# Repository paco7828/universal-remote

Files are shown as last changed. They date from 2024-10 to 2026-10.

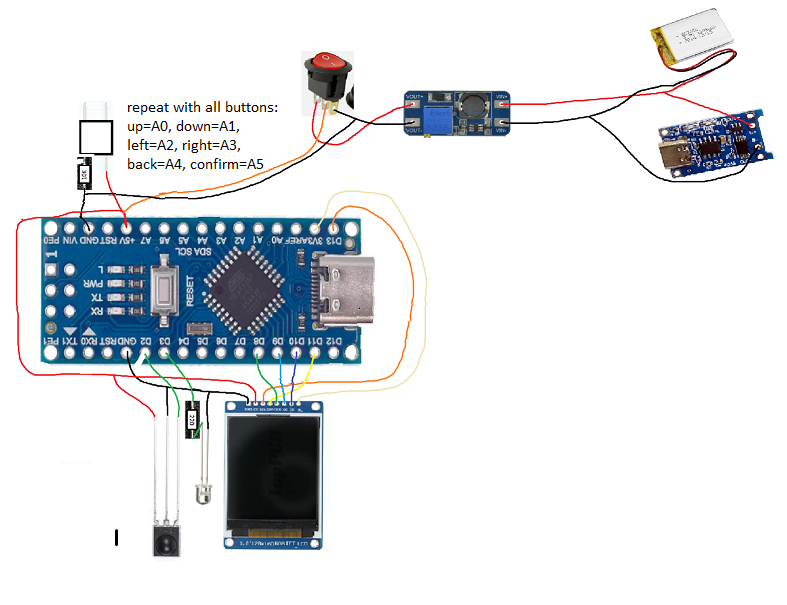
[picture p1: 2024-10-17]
demo/wiring-paint-1.PNG

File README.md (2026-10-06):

# Universal Remote

ESP32-based universal infrared remote control with touch screen.
It can **learn** IR signals, **save them to an SD card**, **resend** them,
and transmit **built-in brand codes**.
The entire UI is touch-controlled, featuring scrollable lists and a virtual
keyboard.

---

## Hardware

| Component | Description |
|---|---|
| MCU | ESP32 (Using FSPI / SPI2 bus) |
| Display | ILI9341 2.4" TFT, 240x320, portrait (rotation 0) |
| Touch | XPT2046 resistive touch, via SPI |
| Storage | MicroSD card |
| IR Transmitter| TSAL6200 |
| IR Receiver | IRM-3638T |

The display and the SD card use **the same SPI bus** (shared MOSI/MISO/CLK),
multiplexed with CS lines. Before sending an IR signal, the code sets `SD_CS` and `TOUCH_CS`
HIGH to avoid bus conflicts.

### Pinout

| Signal | GPIO |
|---|---|
| TFT CS | 7 |
| TFT RST | 10 |
| TFT DC | 2 |
| TFT MOSI | 6 |
| TFT MISO | 5 |
| TFT CLK | 4 |
| Touch CS | 8 |
| Touch IRQ | 9 |
| SD CS | 3 |
| IR TX | 0 |
| IR RX | 1 |

---

## Dependencies

- **LovyanGFX** - display + touch driver (ILI9341 + XPT2046)
- **IRremoteESP8266** - IR receive / send / decode
- **Preferences** - ESP32 NVS (for saving themes)
- **SD**, **SPI** - Arduino ESP32 core built-in
- **`./IR-codes.h`** - custom header with built-in Pronto Hex codes
  (EPSON and NEC arrays). **Without this, the project will not compile.**

---

## Features

### Signal learning (Receive)

1. `Signal options -> Receive` starts listening mode.
2. The receiver decodes the signal into `decode_results`.
3. The code accepts a **maximum of 3 frames** at once within a signal
   (`MAX_FRAMES = 3`), measuring the pause between them as `gap_ms`.
4. Repeat frames and identical frames are discarded.
5. An `UNKNOWN` (raw) signal is only accepted if it is the **first** frame,
   and contains at least 10 pulses, filtering out noise.
6. The captured signal type is determined automatically:
   - `SIG_VALUE` - known protocol, fixed-length value (e.g., NEC)
   - `SIG_STATE` - AC-like protocols with byte-array states
   - `SIG_RAW` - unknown, raw microsecond array
7. After capture, a **QWERTY keyboard** appears to name the signal
   (max 25 characters, letters + `-`).
8. Saved to the SD card: `/saved-signals/<group>/<name>.txt`.

### Signal sending (Transmit)

- **Saved signals**: `Signal options -> Transmit` -> group list -> signal list -> Send.
  The group is the part of the signal's name before the `-` (e.g., `TV-power` -> `TV` group).
- **Built-in signals**: `Built-in signals` -> brand -> signal -> Send.
- **Long pressing** the `Send` button repeats the signal (except for `SIG_STATE` signals).
- Transmission strategy:
  - `SIG_VALUE`: `irsend.send(protocol, value, bits)` - for RC5/RC6,
    the toggle bit switches automatically on each new press.
  - `SIG_STATE`: `irsend.send(protocol, state, bytes)`.
  - `SIG_RAW`: `irsend.sendRaw(rawData, len, khz)`.
  - If protocol sending returns `false`, but raw data is available, an
    automatic **raw fallback** occurs.
- For multi-frame signals, there is a `gap_ms` pause between frames.

### Built-in signals

The `IRCode` structures declared in `IR-codes.h` store the codes in Pronto Hex format.
The firmware converts them to raw microsecond arrays using the `prontoToRawSignal()`
function and calculates the carrier frequency with `prontoCarrierKHz()`.

Currently, **only these** are available from the UI in the `hardcodedBrands[]` array:

- EPSON
- NEC

(Other brands will only appear if you add them to the array.)

### SD Card Management

- **Info** - total / free / used space + number of saved signal files.
- **Files** - file browser with directory navigation, size display,
  and individual file deletion (`Del` button, **!NO CONFIRMATION MESSAGE!**).
- **Format** - keeps the `/System Volume Information` and `/built-in-signals`
  directories, deletes everything else.
- File list limit: 500 items.

### UI / Themes

Three selectable color themes (persisted in NVS):

- Futuristic Red (default)
- Futuristic Green
- Futuristic Purple

Theme switching is displayed with an animated spreading circle effect.

Other UI features:

- Boot splash: `UNIVERSAL / REMOTE` text for ~2 seconds.
- **Scrollable lists** with a sprite buffer (`LGFX_Sprite`) to prevent flickering.
- **Double tap** on a list item = open.
- **Long hold** on a repeatable button = rapid fire (`REPEAT_INTERVAL = 200 ms`).
- Maximum number of buttons per screen: **30**.
- Button style: corner accents + scanline pattern.

---

## Navigation Structure

```
Main Menu
├── Signal options
│   ├── Transmit  ->  [Group]  ->  [Signal list]  ->  Send
│   └── Receive   ->  Listening... ->  Captured!   ->  Keyboard -> Save
├── Built-in signals
│   └── [Brand]   ->  [Signal list] ->  Send
├── SD Card options
│   ├── Info
│   ├── Files  ->  browser (Up / Back / Del)
│   └── Format ->  Yes, format / Cancel formatting
└── Change theme
    ├── Futuristic Red
    ├── Futuristic Green
    └── Futuristic Purple
```

If SD initialization fails, "SD Card options" disappears from the main menu.

---

## Saved signal file format

**Not binary** - each signal is a simple, line-separated `.txt` file:

```
# UniRemote IR signal
name: TV-power
carrier_khz: 38
frame: 1
gap_ms: 40
protocol: NEC
bits: 32
value: 0x20DF10EF
length: 68
raw: 9000,4500,560,560,...
frame: 2
...
```

Fields per frame:

- `gap_ms` - pause before the next frame (only if there is a next frame)
- `protocol` - name returned by `typeToString()`
- `bits` - number of bits for `SIG_VALUE`, bytes×8 for `SIG_STATE`
- `value` - hex value (`SIG_VALUE`)
- `bytes` - space-separated hex bytes (`SIG_STATE`)
- `length` + `raw` - raw microsecond array (always saved if available)

When loading the file, the code automatically determines the `kind` based
on the existing fields: value -> state -> raw priority.

Folder structure:

```
/saved-signals/
├── TV/
│   ├── power.txt
│   └── mute.txt
├── Misc/
│   └── random-signal.txt
```

Names without `-` are automatically placed in the `Misc` group.

---

## File structure

| File | Role |
|---|---|
| `UniversalRemote.ino` | Full firmware |
| `IR-codes.h` | Built-in Pronto Hex codes (EPSON, NEC arrays, `IRCode` struct) |

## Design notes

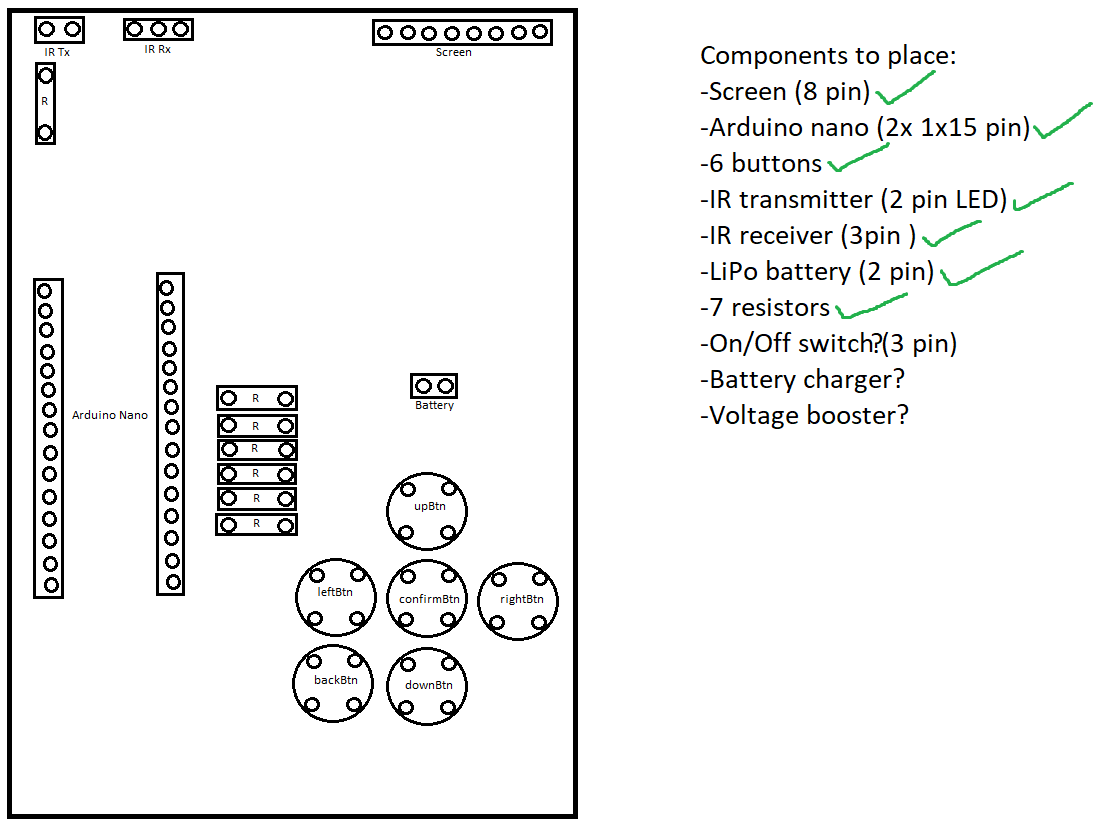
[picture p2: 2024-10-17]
demo/pcb_plan.PNG

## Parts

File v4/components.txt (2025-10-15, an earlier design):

1x ESP32 C3 SUPERMINI - https://www.hestore.hu/prod_10048018.html
3x 100nF 0805 capacitor - https://www.hestore.hu/prod_10001122.html
1x 100uF electrolytic capacitor - https://www.hestore.hu/prod_10039018.html
1x 2.8" TFT Touch display - https://www.hestore.hu/prod_10047949.html
1x 100R 0805 resistor - https://www.hestore.hu/prod_10001142.html
1x 100kR 0805 resistor - https://www.hestore.hu/prod_10001143.html
1x AO3400A - https://www.hestore.hu/prod_10039959.html
1x IRE940-5 - https://www.hestore.hu/prod_10041889.html
1x 22R 1W 2512 resistor - https://www.hestore.hu/prod_10031720.html
1x IRM3638T - https://www.hestore.hu/prod_10045411.html
1x B2B-XH-A - https://www.hestore.hu/prod_10041549.html
1x KCD11-2P - https://www.hestore.hu/prod_10047980.html
1x USB-C-6 pin - https://www.hestore.hu/prod_10046971.html
2x 1N5819HW-7-F - https://www.hestore.hu/prod_10046229.html
1x Red LED 0805 - https://www.hestore.hu/prod_10043215.html
1x Green LED 0805 - https://www.hestore.hu/prod_10036384.html
3x 1kR 0805 resistor - https://www.hestore.hu/prod_10031299.html
2x 10uF 0805 capacitor - https://www.hestore.hu/prod_10032047.html
1x TP4056 - https://www.hestore.hu/prod_10037291.html
1x 1.2kR resistor - https://www.hestore.hu/prod_10001268.html
1x DW01A - https://www.hestore.hu/prod_10046612.html
1x 8205A - https://www.hestore.hu/prod_10045032.html
1x MT3608 - https://www.hestore.hu/prod_10048950.html
1x 22uH 0705 inductor - https://www.hestore.hu/prod_10046500.html
1x 7.5kR 0805 resistor - https://www.hestore.hu/prod_10001197.html

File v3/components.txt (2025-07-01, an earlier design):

ATMEGA328P-AU - https://www.hestore.hu/prod_10032542.html
10k resistor - https://www.hestore.hu/prod_10040338.html
CH340G - https://www.hestore.hu/prod_10036442.html
100nF capacitor - https://www.hestore.hu/prod_10001122.html
3x 22R resistor - https://www.hestore.hu/prod_10001250.html
12MHz crystal - https://www.hestore.hu/prod_10021387.html
16MHz crystal - https://www.hestore.hu/prod_10021434.html
4x 22pF capacitor - https://www.hestore.hu/prod_10001131.html
Micro USB - https://www.hestore.hu/prod_10032693.html
6x SMD button - https://www.hestore.hu/prod_10043772.html
IR transmitter - https://www.hestore.hu/prod_10041889.html
NPN transistor - https://www.hestore.hu/prod_10020924.html
220 resistor - https://www.hestore.hu/prod_10001162.html
IR receiver - https://www.hestore.hu/prod_10045411.html
1.8" TFT screen - https://www.hestore.hu/prod_10045986.html
1x 10uF capacitor - https://www.hestore.hu/prod_10032047.html
Battery protection IC - https://www.hestore.hu/prod_10046612.html
N-channel MOSFET - https://www.hestore.hu/prod_10045032.html
Battery charger IC - https://www.hestore.hu/prod_10037291.html
Green led - https://www.hestore.hu/prod_10036384.html
Red led - https://www.hestore.hu/prod_10043215.html
2x 1k resistors - https://www.hestore.hu/prod_10031299.html
1.2k resistor - https://www.hestore.hu/prod_10001268.html
Battery - https://www.hestore.hu/prod_10036161.html
Battery JST connector - https://www.hestore.hu/prod_10038523.html
Step up converter IC - https://www.hestore.hu/prod_10032041.html
4.7uF capacitor - https://www.hestore.hu/prod_10033975.html
4.7uH inductor - https://www.hestore.hu/prod_10047163.html
1.5M resistor - https://www.hestore.hu/prod_10001251.html
470k resistor - https://www.hestore.hu/prod_10001179.html
Schottky diode - https://www.hestore.hu/prod_10039694.html
Power switch - https://www.hestore.hu/prod_10022003.html

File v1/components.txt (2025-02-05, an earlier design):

-microcontroller - AR-NANOCH-UNS-TYPE-C - https://www.hestore.hu/prod_10044467.html#
-step up module - MT3608-2A - https://www.hestore.hu/prod_10038537.html#
-IR receiver - IRM-3638T - https://www.hestore.hu/prod_10045411.html
-IR blaster - IRE940-5 - https://www.hestore.hu/prod_10041889.html
-power switch - LVSR-12-RD - https://www.hestore.hu/prod_10036786.html
-battery charger module - TP4056-1A-USBC - https://www.hestore.hu/prod_10042093.html
-battery - KXD 383450PL M - https://www.hestore.hu/prod_10036161.html
-Resistors:
    -IR blaster - 220 R 1% - https://www.hestore.hu/prod_10020500.html
    -6x for buttons - 10 K 1% - https://www.hestore.hu/prod_10020541.html
-Screen - 1.8 Inch 8Pin 128*160 RGB TFT LCD Screen Display Module SPI Interface ST7735 IC Driver - https://www.aliexpress.com/i/32988162684.html

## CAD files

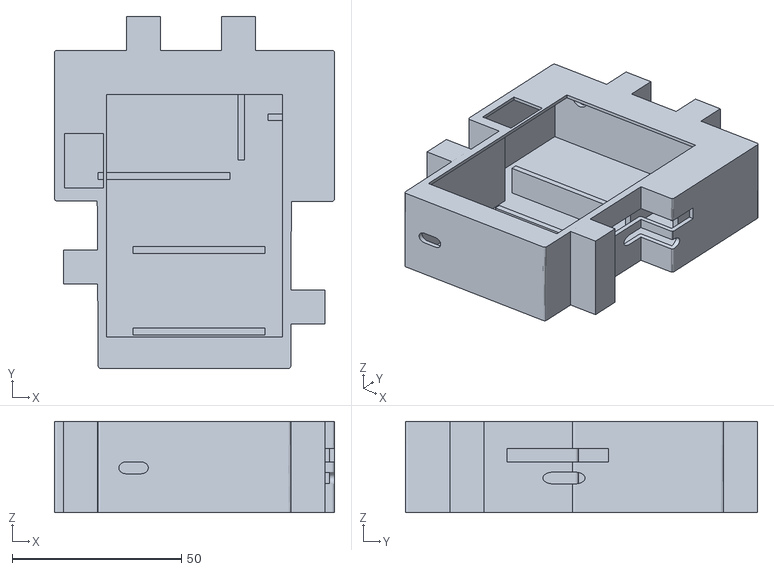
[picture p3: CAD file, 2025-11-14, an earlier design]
v4/uniremote.stl
82.7 x 103.9 x 27.0

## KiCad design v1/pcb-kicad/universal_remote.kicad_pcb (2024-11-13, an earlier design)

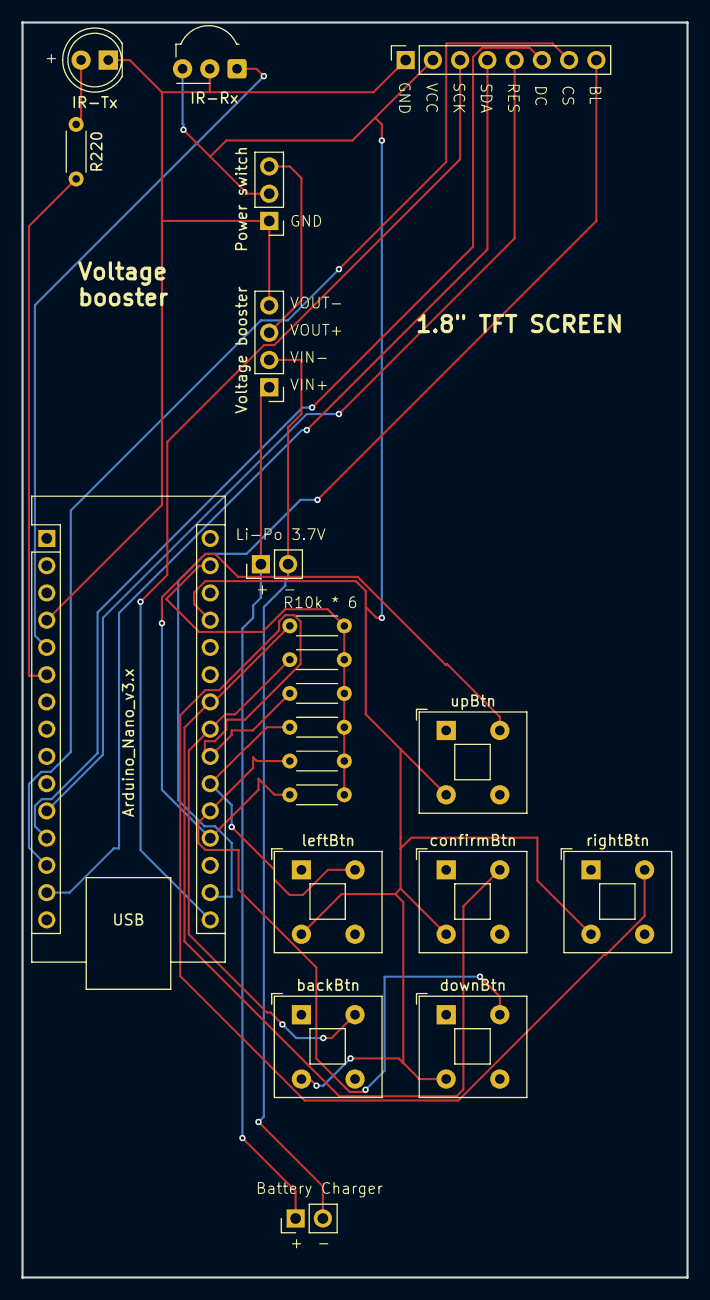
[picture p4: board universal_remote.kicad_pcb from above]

Board: 2 copper layers, 62.0 x 117.0 mm, 21 parts (0 on the bottom side), 21 nets.

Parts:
A1: Arduino_Nano_v3.x; Arduino_Nano
BT1: Li-Po-3.7V; PinHeader_1x02_P2.54mm_Vertical
IR-Tx: IR-Tx; LED_D5.0mm_IRGrey
J1: 1.8TFT-SCREEN; PinSocket_1x08_P2.54mm_Vertical
J2: Battery charger; PinHeader_1x02_P2.54mm_Vertical
J3: Voltage booster; PinHeader_1x04_P2.54mm_Vertical
J4: Power switch; PinHeader_1x03_P2.54mm_Vertical
R2, R3, R4, R5, R6, R7: 1K; R_Axial_DIN0204_L3.6mm_D1.6mm_P5.08mm_Horizontal
R220: 220; R_Axial_DIN0204_L3.6mm_D1.6mm_P5.08mm_Horizontal
U1: IR-Rx; Vishay_MOLD-3Pin
backBtn: backBtn; SW_Push_2P1T_Toggle_CK_PVA1xxH2xxxxxxV2
confirmBtn: confirmBtn; SW_Push_2P1T_Toggle_CK_PVA1xxH2xxxxxxV2
downBtn: downBtn; SW_Push_2P1T_Toggle_CK_PVA1xxH2xxxxxxV2
leftBtn: leftBtn; SW_Push_2P1T_Toggle_CK_PVA1xxH2xxxxxxV2
rightBtn: rightBtn; SW_Push_2P1T_Toggle_CK_PVA1xxH2xxxxxxV2
upBtn: upBtn; SW_Push_2P1T_Toggle_CK_PVA1xxH2xxxxxxV2

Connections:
unnamed: A1.17 (3V3), J1.8
unnamed: A1.27 (+5V), J1.2, J4.2, U1.3 (Vs), backBtn.3 (B), backBtn.4 (B), confirmBtn.3 (B), confirmBtn.4 (B), downBtn.3 (B), downBtn.4 (B), leftBtn.3 (B), leftBtn.4 (B), rightBtn.3 (B), rightBtn.4 (B), upBtn.3 (B), upBtn.4 (B)
unnamed: A1.19 (A0), R2.2, upBtn.1 (A), upBtn.2 (A)
unnamed: A1.20 (A1), R3.2, downBtn.1 (A), downBtn.2 (A)
unnamed: A1.21 (A2), R4.2, leftBtn.1 (A), leftBtn.2 (A)
unnamed: A1.22 (A3), R5.2, rightBtn.1 (A), rightBtn.2 (A)
unnamed: A1.23 (A4), R6.2, backBtn.1 (A), backBtn.2 (A)
unnamed: A1.24 (A5), R7.2, confirmBtn.1 (A), confirmBtn.2 (A)
unnamed: A1.5 (D2), U1.1 (OUT)
unnamed: A1.6 (D3), R220.2
unnamed: A1.11 (D8), J1.5
unnamed: A1.12 (D9), J1.6
unnamed: A1.13 (D10), J1.7
unnamed: A1.14 (D11), J1.4
unnamed: A1.16 (D13), J1.3
unnamed: A1.29 (GND), R2.1, R3.1, R4.1, R5.1, R6.1, R7.1
unnamed: BT1.1 (+), J2.1, J3.1
unnamed: BT1.2 (-), J2.2, J3.2
unnamed: IR-Tx.2 (A), R220.1
unnamed: A1.4 (GND), IR-Tx.1 (K), J1.1, J3.4, J4.1, U1.2 (GND)
unnamed: J3.3, J4.3

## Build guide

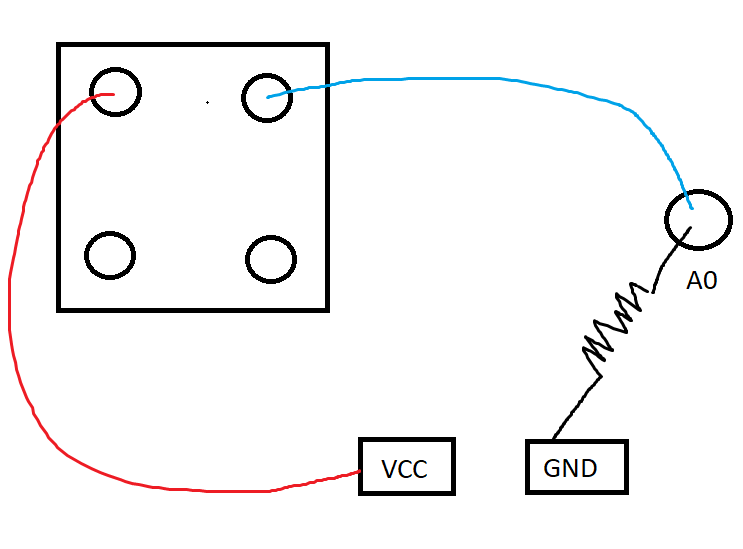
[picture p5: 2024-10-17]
demo/CORRECT_SOLDER.PNG

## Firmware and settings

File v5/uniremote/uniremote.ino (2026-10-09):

#define LGFX_USE_V1
#include <LovyanGFX.hpp>
#include <SPI.h>
#include <SD.h>
#include <IRremoteESP8266.h>
#include <IRrecv.h>
#include <IRsend.h>
#include <IRutils.h>
#include <Preferences.h>
#include <functional>
#include <vector>
#include <algorithm>
#include "./IR-codes.h"

// ============================================================
// Layout of this file
//   1. Pins, display driver
//   2. Constants, types, theme presets
//   3. Function prototypes (grouped by module)
//   4. Static data (menu tables, built-in brand table)
//   5. Global state (grouped by module)
//   6. Setup & loop
//   7. UI core: display chrome, touch & buttons, scroll list engine
//   8. IR engine, signal storage (SD), SD utilities
//   9. Screens: main menu, signals, built-in, SD card, theme
// ============================================================

// ============================================================
// Pin definitions
// ============================================================
constexpr uint8_t TFT_CS = 7;
constexpr uint8_t TFT_RST = 10;
constexpr uint8_t TFT_DC = 2;
constexpr uint8_t TFT_MOSI = 6;
constexpr uint8_t TFT_MISO = 5;
constexpr uint8_t TFT_CLK = 4;
constexpr uint8_t TOUCH_CS = 8;
constexpr uint8_t TOUCH_IRQ = 9;
constexpr uint8_t SD_CS = 3;
constexpr uint8_t IR_TX = 0;
constexpr uint8_t IR_RX = 1;

// ============================================================
// Display driver
// ============================================================
class LGFX : public lgfx::LGFX_Device {
  lgfx::Panel_ILI9341 _panel_instance;
  lgfx::Bus_SPI _bus_instance;
  lgfx::Touch_XPT2046 _touch_instance;
public:
  LGFX(void) {
    {
      auto cfg = _bus_instance.config();
      cfg.spi_host = SPI2_HOST;
      cfg.spi_mode = 0;
      cfg.freq_write = 40000000;
      cfg.freq_read = 16000000;
      cfg.pin_sclk = TFT_CLK;
      cfg.pin_mosi = TFT_MOSI;
      cfg.pin_miso = -1;
      cfg.pin_dc = TFT_DC;
      _bus_instance.config(cfg);
      _panel_instance.setBus(&_bus_instance);
    }
    {
      auto cfg = _panel_instance.config();
      cfg.pin_cs = TFT_CS;
      cfg.pin_rst = TFT_RST;
      cfg.panel_width = 240;
      cfg.panel_height = 320;
      _panel_instance.config(cfg);
    }
    {
      auto cfg = _touch_instance.config();
      cfg.x_min = 3850;
      cfg.x_max = 240;
      cfg.y_min = 250;
      cfg.y_max = 3750;
      cfg.pin_sclk = TFT_CLK;
      cfg.pin_mosi = TFT_MOSI;
      cfg.pin_miso = TFT_MISO;
      cfg.pin_cs = TOUCH_CS;
      cfg.pin_int = TOUCH_IRQ;
      cfg.bus_shared = true;
      cfg.spi_host = SPI2_HOST;
      cfg.freq = 1000000;
      _touch_instance.config(cfg);
      _panel_instance.setTouch(&_touch_instance);
    }
    setPanel(&_panel_instance);
  }
};

// ============================================================
// Constants
// ============================================================
// --- UI layout: scroll list viewport shared by every list screen ---
constexpr int LIST_VIEW_X = 5;
constexpr int LIST_VIEW_Y = 26;
constexpr int LIST_VIEW_W = 230;
constexpr int LIST_VIEW_H = 228;
constexpr int LIST_BUTTON_Y = 260;

// --- Touch timing ---
constexpr unsigned long REPEAT_INTERVAL = 200;
constexpr int SCROLL_DRAG_THRESHOLD = 10;
constexpr unsigned long DOUBLE_TAP_WINDOW = 400;

// --- IR capture / transmit ---
constexpr uint16_t IR_CAPTURE_BUFFER = 1024;
constexpr uint8_t IR_CAPTURE_TIMEOUT_MS = 35;
constexpr uint16_t IR_FRAME_WINDOW_MS = 400;
constexpr uint8_t MAX_FRAMES = 3;
constexpr uint16_t MAX_RAW_PULSES = 400;
constexpr uint8_t DEFAULT_CARRIER_KHZ = 38;
constexpr uint16_t IR_DEFAULT_GAP_MS = 40;
constexpr uint16_t IR_VARIANT_GAP_MS = 50;
constexpr float PRONTO_CLOCK_US = 0.241246f;

// --- Signal storage on SD ---
constexpr const char *SAVED_ROOT = "/saved-signals";
constexpr const char *SIGNAL_EXT = ".txt";
constexpr int MAX_SAVED_SIGNAL_CHARS = 25;
constexpr int SD_FILES_MAX = 500;

// ============================================================
// Types
// ============================================================
enum SignalKind : uint8_t { SIG_RAW = 0,
                            SIG_VALUE = 1,
                            SIG_STATE = 2 };
enum CaptureResult : uint8_t { CAP_IGNORED,
                               CAP_INVALID,
                               CAP_OK };

struct IRSignal {
  char name[MAX_SAVED_SIGNAL_CHARS + 1];
  SignalKind kind;
  decode_type_t protocol;
  uint16_t bits;
  uint64_t value;
  uint8_t state[kStateSizeMax];
  uint8_t carrierKHz;
  uint16_t rawData[MAX_RAW_PULSES];
  uint16_t rawDataLen;
  uint16_t gapAfterMs;
};

struct TouchButton {
  int x, y, w, h;
  uint16_t color;
  const char *label;
  void (*callback)();
  bool pressed, isBackButton, repeatable;
};

using RowRenderer = std::function<void(int idx, int y, int rowH, bool selected)>;

struct ScrollList {
  int itemCount = 0;
  int rowHeight = 32;
  int selectedIndex = -1;
  float scrollPx = 0;
  int viewX = 0, viewY = 0, viewW = 0, viewH = 0;
  RowRenderer renderRow;
  std::function<void()> onOpen = nullptr;
  std::function<void()> onSelect = nullptr;
};

struct Option {
  const char *name;
  void (*callback)();
};

struct ThemeColors {
  uint16_t primary, secondary, accent, dark, darkest;
};

struct HardcodedBrand {
  const char *brandName;
  const IRCode *codes;
  uint8_t codesLength;
};

// ============================================================
// Theme presets
// ============================================================
const ThemeColors THEME_FUTURISTIC_RED = { 0xF800, 0xD000, 0x8800, 0x4208, 0x2104 };
const ThemeColors THEME_FUTURISTIC_GREEN = { 0x07E0, 0x05C0, 0x0400, 0x4208, 0x2104 };
const ThemeColors THEME_FUTURISTIC_PURPLE = { 0xF81F, 0xC81F, 0x8010, 0x4208, 0x2104 };

// ============================================================
// Function prototypes
// ============================================================
// Setup & loop
void initHardware();
void pollIRCapture();
void pollTouch();

// Display chrome
void clearScreen();
void beginScreen();
void drawHeaderFooter();
void drawTitle(const char *title, uint16_t x = 90, uint16_t y = 305);
void drawBackBtn(uint8_t x, uint8_t y, uint8_t w, uint8_t h, void (*cb)());
void printCentered(const char *text, int y, uint16_t color, uint8_t size);
void showEmptyScreen(const char *line1, const char *line2, int y, void (*backCb)(), const char *title, uint16_t titleX);
void drawBootSplash();

// Touch & buttons
int processTouchButtons(int tx, int ty);
bool isTouchInButton(TouchButton *btn, int tx, int ty);
void drawButton(TouchButton *btn, bool active);
void createTouchBox(int x, int y, int w, int h, uint16_t color, const char *label, void (*cb)(), bool isBack = false, bool repeatable = false);
void createOptions(const Option opts[], int count, int x = 10, int y = 50, int bw = 220, int bh = 45);

// Scroll list engine
bool pointInScrollView(ScrollList *list, int x, int y);
void ensureListSprite(int w, int h);
void clampScroll(ScrollList &list);
void renderScrollList(ScrollList &list);
void setupAndRenderScrollList(int count, int rowH, RowRenderer renderer);
void resetListSelection();
bool selectionValid(size_t count);
void drawListRow(int y, int rowH, bool selected, const String &text, uint8_t textSize = 2);

// IR engine
CaptureResult captureFrame(const decode_results &r, unsigned long nowMs);
void transmitSignal(const IRSignal &signal);
void transmitSequence(const IRSignal *frames, uint8_t count);
uint8_t prontoCarrierKHz(const uint16_t *pronto);
uint16_t prontoToRawSignal(const uint16_t *pronto, uint16_t *outRaw);
uint8_t codeVariants(const IRCode &code);
void sendBuiltInVariant(const IRCode &code, uint8_t variant);

// Signal storage (SD)
void sortNames(std::vector<String> &v);
void splitSignalName(const char *full, String &group, String &file);
void migrateFlatSignals();
bool isSignalFile(const String &fileName);
String stripSignalExt(String fileName);
void saveSignalToSD(const IRSignal *frames, uint8_t count);
bool loadSignalFromSD(const String &fileName, IRSignal *frames, uint8_t &count);

// SD utilities
String formatBytes(uint64_t bytes);
int countFilesInDirectory(const char *path);
bool deleteDirectory(const char *path);
void formatStatusLine(const char *label, uint16_t labelColor, const String &name);

// Screens: main menu
void drawMenuUI();

// Screens: signals (transmit / receive / keyboard)
void signalOptions();
void listSavedSignals();
void drawSavedSignalsList();
void listGroupedSignals();
void drawGroupedSignalsList();
void startSignalListen();
void drawKeyboard();
void keyboardButtonPressed();
void leaveKeyboard();

// Screens: built-in signals
void builtInSignalsBrowser();
void listBuiltInSignals();
void listBuiltInVariants();
void updateBuiltInButtons(bool force);

// Screens: SD card
void sdData();
void listSDInfo();
void listSDFiles();
void browseSDPath(const String &path);
void loadSDFiles(const String &path);
void drawSDFileBrowser();
void sdFormatOptions();
void formatSD();
void deleteSelectedFile();

// Screens: theme
void themeOptions();
void setThemeFuturisticRed();
void setThemeFuturisticGreen();
void setThemeFuturisticPurple();
ThemeColors themeFromIndex(uint8_t idx);
void setTheme(uint8_t themeIndex);

// ============================================================
// Static data (menus & brand library)
// ============================================================
const Option MENU_OPTIONS[] = {
  { "Signal options", signalOptions },
  { "Built-in signals", builtInSignalsBrowser },
  { "SD Card options", sdData },
  { "Change theme", themeOptions }
};
const Option MENU_OPTIONS_NO_SD[] = {
  { "Signal options", signalOptions },
  { "Built-in signals", builtInSignalsBrowser },
  { "Change theme", themeOptions }
};
const Option SD_CARD_OPTIONS[] = {
  { "Info", listSDInfo },
  { "Files", listSDFiles },
  { "Format", sdFormatOptions },
  { "Back", drawMenuUI }
};
const Option SD_FORMAT_OPTIONS[] = {
  { "Yes, format", formatSD },
  { "Cancel formatting", sdData }
};
const Option THEME_OPTIONS[] = {
  { "Futuristic Red", setThemeFuturisticRed },
  { "Futuristic Green", setThemeFuturisticGreen },
  { "Futuristic Purple", setThemeFuturisticPurple },
  { "Back", drawMenuUI }
};

const HardcodedBrand hardcodedBrands[] = {
  { "EPSON", EPSON_CODES, EPSON_CODES_LENGTH },
  { "NEC", NEC_CODES, NEC_CODES_LENGTH },
  { "MIDEA", MIDEA_CODES, MIDEA_CODES_LENGTH }
};
const uint8_t hardcodedBrandsLength = sizeof(hardcodedBrands) / sizeof(hardcodedBrands[0]);

// ============================================================
// Global state
// ============================================================
// --- Display & preferences ---
LGFX tft;
SPIClass spiSD(FSPI);
ThemeColors currentTheme;
Preferences prefs;
bool initializedSD = false;

// --- Button system ---
TouchButton buttons[30];
uint8_t buttonCount = 0;
uint8_t activeBtnIndex = 0;

// --- Touch / gesture ---
bool touchHeld = false;
int heldButtonIndex = -1;
unsigned long lastRepeatFire = 0;
bool scrollGestureActive = false;
bool scrollIsDragging = false;
int32_t scrollStartY = 0;
float scrollStartPx = 0;
int lastTapIndex = -1;
unsigned long lastTapTime = 0;

// --- Scroll list engine ---
LGFX_Sprite listSprite(&tft);
bool listSpriteReady = false;
ScrollList activeList;
ScrollList *activeScrollList = nullptr;

// --- IR ---
IRrecv irrecv(IR_RX, IR_CAPTURE_BUFFER, IR_CAPTURE_TIMEOUT_MS, true);
IRsend irsend(IR_TX);
decode_results irResults;
IRSignal capturedFrames[MAX_FRAMES];
uint8_t capturedFrameCount = 0;
unsigned long lastFrameMs = 0;
bool signalCaptured = false;
bool listeningForSignal = false;
bool rcToggle = false;

// --- Saved signals browser ---
std::vector<String> savedSignalGroups;
std::vector<String> groupedSignalFiles;
String currentSavedGroup = "";
String sendCachePath;

// --- Built-in signals browser ---
const IRCode *currentBrandCodes = nullptr;
uint8_t currentBrandCodesLength = 0;
String currentBrandName = "";
const IRCode *currentCode = nullptr;

// --- SD file browser ---
std::vector<String> sdFiles;
String currentPath = "/";

// --- Keyboard ---
const char *const qwerty0[10] = { "Q", "W", "E", "R", "T", "Y", "U", "I", "O", "P" };
const char *const qwerty1[9] = { "A", "S", "D", "F", "G", "H", "J", "K", "L" };
const char *const qwerty2[7] = { "Z", "X", "C", "V", "B", "N", "M" };
char outputText[MAX_SAVED_SIGNAL_CHARS + 1] = "";

// ============================================================
// Setup & loop
// ============================================================
void setup() {
  initHardware();
}

void loop() {
  if (listeningForSignal && !signalCaptured) pollIRCapture();
  pollTouch();
  delay(listeningForSignal ? 1 : 10);
}

void pollIRCapture() {
  if (irrecv.decode(&irResults)) {
    unsigned long now = millis();
    CaptureResult cr = captureFrame(irResults, now);
    if (cr == CAP_INVALID) {
      beginScreen();
      printCentered("Invalid", 120, currentTheme.primary, 2);
      printCentered("signal!", 140, currentTheme.primary, 2);
      delay(2000);
      startSignalListen();
    }
  }

  bool done = capturedFrameCount > 0 && (capturedFrames[0].kind == SIG_RAW || capturedFrameCount >= MAX_FRAMES || millis() - lastFrameMs > IR_FRAME_WINDOW_MS);
  if (done) {
    irrecv.disableIRIn();
    signalCaptured = true;
    listeningForSignal = false;
    beginScreen();
    printCentered("Captured!", 150, currentTheme.primary, 2);
    delay(1500);
    drawKeyboard();
  }
}

void pollTouch() {
  int32_t tx, ty;
  bool touching = tft.getTouch(&tx, &ty);

  if (touching) {
    if (!touchHeld) {
      touchHeld = true;
      if (pointInScrollView(activeScrollList, (int)tx, (int)ty)) {
        scrollGestureActive = true;
        scrollIsDragging = false;
        scrollStartY = ty;
        scrollStartPx = activeScrollList->scrollPx;
        heldButtonIndex = -1;
      } else {
        scrollGestureActive = false;
        heldButtonIndex = processTouchButtons((int)tx, (int)ty);
        lastRepeatFire = millis();
      }
    } else if (scrollGestureActive && activeScrollList) {
      int32_t delta = ty - scrollStartY;
      if (!scrollIsDragging && abs((int)delta) > SCROLL_DRAG_THRESHOLD)
        scrollIsDragging = true;
      if (scrollIsDragging) {
        activeScrollList->scrollPx = scrollStartPx - delta;
        clampScroll(*activeScrollList);
        renderScrollList(*activeScrollList);
      }
    } else if (heldButtonIndex >= 0 && heldButtonIndex < buttonCount) {
      TouchButton *btn = &buttons[heldButtonIndex];
      if (btn->repeatable && isTouchInButton(btn, (int)tx, (int)ty)) {
        unsigned long now = millis();
        if (now - lastRepeatFire > REPEAT_INTERVAL) {
          lastRepeatFire = now;
          if (btn->callback) btn->callback();
          if (heldButtonIndex < buttonCount) {
            buttons[heldButtonIndex].pressed = true;
            drawButton(&buttons[heldButtonIndex], true);
          }
        }
      }
    }
    delay(scrollIsDragging ? 16 : 50);

  } else {
    if (scrollGestureActive && !scrollIsDragging && activeScrollList) {
      int relY = scrollStartY - activeScrollList->viewY;
      int tapped = (int)((activeScrollList->scrollPx + relY) / activeScrollList->rowHeight);
      if (tapped >= 0 && tapped < activeScrollList->itemCount) {
        unsigned long now = millis();
        bool isDoubleTap = (tapped == lastTapIndex) && (now - lastTapTime < DOUBLE_TAP_WINDOW);
        activeScrollList->selectedIndex = tapped;
        renderScrollList(*activeScrollList);
        if (isDoubleTap && activeScrollList->onOpen) {
          lastTapIndex = -1;
          activeScrollList->onOpen();
        } else {
          lastTapIndex = tapped;
          lastTapTime = now;
          if (activeScrollList->onSelect) activeScrollList->onSelect();
        }
      }
    }
    scrollGestureActive = false;
    scrollIsDragging = false;
    touchHeld = false;
    heldButtonIndex = -1;
    for (int i = 0; i < buttonCount; i++) {
      if (buttons[i].pressed) {
        buttons[i].pressed = false;
        drawButton(&buttons[i], false);
      }
    }
  }
}

void initHardware() {
  prefs.begin("uniremote", true);
  currentTheme = themeFromIndex(prefs.getUChar("theme", 0));
  prefs.end();

  irsend.begin();

  for (uint8_t cs : { TFT_CS, TOUCH_CS, SD_CS }) {
    pinMode(cs, OUTPUT);
    digitalWrite(cs, HIGH);
  }

  spiSD.begin(TFT_CLK, TFT_MISO, TFT_MOSI, SD_CS);
  initializedSD = SD.begin(SD_CS, spiSD, 20000000);
  if (initializedSD) {
    if (!SD.exists(SAVED_ROOT)) SD.mkdir(SAVED_ROOT);
    migrateFlatSignals();
  }

  tft.init();
  tft.setRotation(0);
  drawBootSplash();
}

// ============================================================
// Display chrome
// ============================================================
void clearScreen() {
  tft.fillRect(0, 10, 240, 308, TFT_BLACK);
  drawHeaderFooter();
}

void drawHeaderFooter() {
  activeScrollList = nullptr;
  activeList.onOpen = nullptr;
  activeList.onSelect = nullptr;
  lastTapIndex = -1;
  tft.drawFastHLine(0, 6, 239, currentTheme.primary);
  for (int i = 0; i < 15; i++) {
    tft.drawPixel(i, 2 + i / 3, currentTheme.primary);
    tft.drawPixel(239 - i, 2 + i / 3, currentTheme.primary);
  }
  tft.drawFastHLine(0, 318, 240, currentTheme.primary);
  for (int i = 0; i < 15; i++) {
    tft.drawPixel(i, 317 - i / 3, currentTheme.primary);
    tft.drawPixel(239 - i, 317 - i / 3, currentTheme.primary);
  }
}

void drawTitle(const char *title, uint16_t x, uint16_t y) {
  tft.setTextSize(1);
  tft.setTextColor(currentTheme.primary);
  tft.setCursor(x, y);
  tft.println(title);
}

void printCentered(const char *text, int y, uint16_t color, uint8_t size) {
  tft.setTextSize(size);
  tft.setTextColor(color);
  tft.setCursor((240 - tft.textWidth(text)) / 2, y);
  tft.print(text);
}

void drawBackBtn(uint8_t x, uint8_t y, uint8_t w, uint8_t h, void (*cb)()) {
  createTouchBox(x, y, w, h, currentTheme.secondary, "Back", cb, true);
}

void drawBootSplash() {
  tft.fillScreen(TFT_BLACK);
  drawHeaderFooter();
  printCentered("UNIVERSAL", 120, currentTheme.primary, 3);
  printCentered("REMOTE", 155, currentTheme.primary, 3);
  delay(2000);
  drawMenuUI();
}

// Fresh screen: drops all buttons, clears the body, redraws header/footer
void beginScreen() {
  buttonCount = 0;
  clearScreen();
}

// Shared "empty list" screen: two centered lines, Back button, title
void showEmptyScreen(const char *line1, const char *line2, int y, void (*backCb)(), const char *title, uint16_t titleX) {
  printCentered(line1, y, currentTheme.primary, 2);
  printCentered(line2, y + 20, currentTheme.primary, 2);
  drawBackBtn(60, 200, 120, 40, backCb);
  drawTitle(title, titleX);
}

// ============================================================
// Touch & buttons
// ============================================================
int processTouchButtons(int tx, int ty) {
  for (int i = 0; i < buttonCount; i++) {
    if (isTouchInButton(&buttons[i], tx, ty)) {
      buttons[i].pressed = true;
      drawButton(&buttons[i], true);
      activeBtnIndex = i;
      if (buttons[i].callback) buttons[i].callback();
      return i;
    }
  }
  return -1;
}

void createTouchBox(int x, int y, int w, int h, uint16_t color, const char *label, void (*cb)(), bool isBack, bool repeatable) {
  TouchButton *btn = &buttons[buttonCount];
  btn->x = x;
  btn->y = y;
  btn->w = w;
  btn->h = h;
  btn->color = color;
  btn->label = label;
  btn->callback = cb;
  btn->pressed = false;
  btn->isBackButton = isBack;
  btn->repeatable = repeatable;
  drawButton(btn, false);
  buttonCount++;
}

bool isTouchInButton(TouchButton *btn, int tx, int ty) {
  return tx >= btn->x && tx <= btn->x + btn->w && ty >= btn->y && ty <= btn->y + btn->h;
}

void drawButton(TouchButton *btn, bool active) {
  if (btn->isBackButton) active = !active;
  const uint16_t borderColor = active ? TFT_WHITE : btn->color;
  const int cs = 8;

  tft.startWrite();
  tft.fillRect(btn->x, btn->y, btn->w, btn->h, TFT_BLACK);
  if (active) {
    tft.fillRect(btn->x, btn->y, btn->w, btn->h, btn->color);
    tft.drawRect(btn->x, btn->y, btn->w, btn->h, TFT_WHITE);
  } else {
    tft.drawRect(btn->x - 1, btn->y - 1, btn->w + 2, btn->h + 2, currentTheme.accent);
    tft.drawRect(btn->x - 2, btn->y - 2, btn->w + 4, btn->h + 4, currentTheme.darkest);
    tft.fillRect(btn->x, btn->y, btn->w, btn->h, TFT_BLACK);
    tft.drawRect(btn->x, btn->y, btn->w, btn->h, btn->color);
    for (int j = 2; j < btn->h - 2; j += 5)
      tft.drawFastHLine(btn->x + 2, btn->y + j, btn->w - 4, currentTheme.darkest);
  }
  tft.drawFastHLine(btn->x, btn->y, cs, borderColor);
  tft.drawFastVLine(btn->x, btn->y, cs, borderColor);
  tft.drawFastHLine(btn->x + btn->w - cs, btn->y, cs, borderColor);
  tft.drawFastVLine(btn->x + btn->w - 1, btn->y, cs, borderColor);
  tft.drawFastHLine(btn->x, btn->y + btn->h - 1, cs, borderColor);
  tft.drawFastVLine(btn->x, btn->y + btn->h - cs, cs, borderColor);
  tft.drawFastHLine(btn->x + btn->w - cs, btn->y + btn->h - 1, cs, borderColor);
  tft.drawFastVLine(btn->x + btn->w - 1, btn->y + btn->h - cs, cs, borderColor);

  tft.setTextSize(2);
  int16_t tw = tft.textWidth(btn->label), th = tft.fontHeight();
  tft.setTextColor(active ? TFT_BLACK : btn->color, active ? btn->color : TFT_BLACK);
  tft.setCursor(btn->x + (btn->w - tw) / 2, btn->y + (btn->h - th) / 2);
  tft.print(btn->label);
  tft.endWrite();
}

void createOptions(const Option opts[], int count, int x, int y, int bw, int bh) {
  beginScreen();
  for (int i = 0; i < count; i++) {
    bool isBack = (i == count - 1 && strcmp(opts[i].name, "Back") == 0);
    createTouchBox(x, y + 15 + (bh + 5) * i, bw, bh, currentTheme.primary, opts[i].name, opts[i].callback, isBack);
  }
}
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

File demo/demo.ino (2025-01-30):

// Import necessary libraries
#include <IRremote.hpp>
#include <EEPROM.h>

// Define IR signal receiver and transmitter pins
const int IR_RECV_PIN = 2;
const int IR_SEND_PIN = 3;

// Define IR signal structure
struct IRSignal {
  char name[10];            // Signal name
  uint16_t rawData[68];     // Fixed length
  uint8_t rawDataLen;       // Length of raw data
} __attribute__((packed));  // Prevents memory alignment issues

// Buffer for capturing IR signals
uint16_t currentRawData[68];  
uint8_t currentRawDataLen;
#define MARK_EXCESS_MICROS 20

// State variables
bool signalCaptured = false;
unsigned long lastTransmitTime = 0;
const unsigned long TRANSMIT_INTERVAL = 3000;  // 3 seconds

void setup() {
  Serial.begin(115200);
  IrSender.begin(IR_SEND_PIN);
  IrReceiver.begin(IR_RECV_PIN);  // FIXED: Removed ENABLE_LED_FEEDBACK

  Serial.println("IR Remote Ready!");
  Serial.println("Waiting for signal...");
}

void loop() {
  if (!signalCaptured) {
    if (IrReceiver.decode()) {
      Serial.println("\nSignal received!");

      // Capture the raw data
      captureRawData();

      // Create signal structure
      IRSignal signal;
      strcpy(signal.name, "Signal1");  
      memcpy(signal.rawData, currentRawData, currentRawDataLen * sizeof(uint16_t));
      signal.rawDataLen = currentRawDataLen;

      // Debug print the captured data
      Serial.println("Captured raw data:");
      printRawData(signal.rawData, signal.rawDataLen);

      // Save to EEPROM
      saveIRSignal(signal);

      signalCaptured = true;
      lastTransmitTime = millis();

      Serial.println("Signal saved to EEPROM");
      Serial.println("Starting periodic transmission...");
      
      IrReceiver.resume();  // FIXED: Immediately resume receiver
    }
  } else {
    if (millis() - lastTransmitTime >= TRANSMIT_INTERVAL) {
      Serial.println("\nReading signal from EEPROM and transmitting...");

      // Read from EEPROM
      IRSignal savedSignal = readSignalAtIndex(0);

      // Debug print the read data
      Serial.println("Data read from EEPROM:");
      printRawData(savedSignal.rawData, savedSignal.rawDataLen);

      // Send the signal
      sendIRSignal(savedSignal);
      Serial.println("Signal transmitted!");

      lastTransmitTime = millis();
    }
  }
}

// --- FIXED CAPTURE FUNCTION ---
void captureRawData() {
  currentRawDataLen = IrReceiver.decodedIRData.rawlen - 1;
  
  if (currentRawDataLen > 68) {
    Serial.println("ERROR: Raw data too long! Truncating.");
    currentRawDataLen = 68;
  }

  Serial.print("Capturing raw data, length: ");
  Serial.println(currentRawDataLen);

  for (uint8_t i = 1; i < IrReceiver.decodedIRData.rawlen; i++) {
    uint32_t duration = IrReceiver.decodedIRData.rawDataPtr->rawbuf[i] * MICROS_PER_TICK;

    if (i % 2 == 1) {  // Mark
      duration -= MARK_EXCESS_MICROS;
    } else {  // Space
      duration += MARK_EXCESS_MICROS;
    }

    if (duration > 65535) {
      Serial.println("WARNING: Overflow detected in raw data!");
      duration = 65535;
    }

    currentRawData[i - 1] = (uint16_t)duration;
  }
}

// --- FIXED SENDING FUNCTION ---
void sendIRSignal(const IRSignal &signal) {
  Serial.println("Sending IR signal:");
  printRawData(signal.rawData, signal.rawDataLen);

  IrSender.sendRaw(signal.rawData, signal.rawDataLen, 38);
  delay(50);
}

// --- EEPROM FUNCTIONS ---
void saveIRSignal(const IRSignal &signal) {
  int address = 0;  // Always overwrite first slot
  EEPROM.put(address, signal);
  Serial.println("Signal saved successfully");
}

IRSignal readSignalAtIndex(int index) {
  IRSignal signal;
  int address = index * sizeof(IRSignal);
  EEPROM.get(address, signal);
  return signal;
}

// --- DEBUG FUNCTION ---
void printRawData(uint16_t *data, uint8_t length) {
  for (uint8_t i = 0; i < length; i++) {
    Serial.print(data[i]);
    Serial.print(", ");
    if ((i + 1) % 8 == 0) {
      Serial.println();
    }
  }
  Serial.println();
}

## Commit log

2024-11-03 Uploaded corrected version of the PCB
    Problems with first version of the PCB:
    -The power switch's positive and negative pin wasn't connected to the microcontroller's circuit
    -The buttons' top left and bottom left pin are connected by default => when button was soldered it was reacting as it was pressed => switched the top left pin to top right at all buttons
    [universal_remote-B_Cu.gbr, universal_remote-B_Mask.gbr, universal_remote-B_Paste.gbr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]
2024-11-13 Re-arranged file
    [universal_remote-B_Cu.gbr, universal_remote-B_Mask.gbr, universal_remote-B_Paste.gbr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]
2025-02-01 Fixed callback errors, checkMemory and back to menu works.
    [UniversalRemote.h]
2025-02-01 Added listen for signal, fix needed, fixed other bugs.
    [UniversalRemote.h]
2025-02-02 Added keyboard and functionality, outputText isnt shown correctly, needs fix.
    [UniversalRemote.h]
2025-02-02 Fixed keyboard and state errors.
    [UniversalRemote.h]
2025-02-02 Backup save for further fixes.
    [UniversalRemote.h]
2025-02-02 Fixed checkmemory and memoryFormat functions, saved signals needs fix.
    [UniversalRemote.h]
2025-02-02 Modified the listmemorydata so it prints the signal names on serial only.
2025-02-03 Added correct signal saving and outputting, confirmation isnt working at keyboard.
    [UniversalRemote.h]
2025-02-03 Fixed signal saving and retrieval and displaying.
    [UniversalRemote.h]
2025-02-03 Correct saving, displaying, deleting signals, 2 UI fixes needed and state handlers inside class.
    [UniversalRemote.h]
2025-02-03 Fixed inspectionChoice reset on returning to menu.
    [UniversalRemote.h]
2025-02-05 Rearranged file structure and added first version's components.
    [universal_remote-B_Cu.gbr, universal_remote-B_Mask.gbr, universal_remote-B_Paste.gbr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]
2025-03-06 Added header v2 with instructions to button usage without resistors to gnd.
2025-04-06 Added JST connector to components.
2025-04-13 Added 22 ohm resistors for ch340G D+ and D- data lines.
2025-04-13 Added 12MHz crystal and 2x 22pF capacitors for CH340G.
2025-07-01 Fixed errors, removed unnecessary files and parts, added PCB design for V3.
    [UniversalRemote.h, uniremote.ino]
2025-07-16 Small fixes for final code.
    [UniversalRemote.h, uniremote.ino]
2025-10-11 Added v4 version's demo code with freeze functions for esp32 c3 supermini instead of arduino.
2025-10-11 Added ir led strip codes to IR-codes.h.
2025-10-12 Added functions for correct compiling.
    [uniremote.ino]
2025-10-12 Fixed code's compilation errors and projector brands' options' height.
    [uniremote.ino]
2025-10-12 Added grid creator function and styled back button so it stands out from the general buttons.
2025-10-12 Added correct spacing for transmit and receive options and sd card options.
    [uniremote.ino]
2025-10-13 Added touch button debounce and titles. Removed backToMenu and changed to drawMenuUI.
2025-10-13 Added initialization without SD card so SD card options aren't available. Back button has been inserted to listSDInfo function with new drawBackBtn.
2025-10-26 Added v4 gerber files.
2025-10-26 Added new gerber files with enclosure.
2025-10-26 Added universal-remote enclosure v1.
2025-10-26 ADded signature and project name to pcb.
2025-11-14 Added v1 shell.
    [uniremote.stl]
2026-06-08 Revise README for ESP32 universal IR remote
    Updated README to reflect new features and hardware details for the ESP32-based universal IR remote.
2026-06-08 Added v4 assembled device images.
2026-06-16 Added V5 demo code and pcb.
    [uniremote.stl]
2026-06-26 Fixed mosfet orientation for v5 pcb
2026-06-27 Changed 2.2R resistor to 10R resistor at v5 pcb.
2026-09-30 Changed file saving logic from .bin to .txt to be more user friendly. Added correct LovyanGFX lib.
    [uniremote.ino]
2026-10-06 Refactor IR capture and signal storage
    This change adds multi-variant built-in IR codes, upgrades the IR stack to IRremoteESP8266, and reorganizes the sketch around structured capture/transmit flows. It also introduces grouped saved-signa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
2026-10-06 Code-cleanup and new readme.
    Removed left-in hungarian comments and serial messages (there are some empty else branches, future error handling needed). Updated README.md with new code structure and logic.
    [uniremote.ino]
2026-10-09 Update IR-codes.h with Midea power toggle.
